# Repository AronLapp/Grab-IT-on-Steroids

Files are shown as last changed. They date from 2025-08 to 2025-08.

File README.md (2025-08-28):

# Grab-IT-on-Steroids

Making a Joy-IT Grab-it robot arm compatible with algorithm-driven control

# Purpose

This Project aims to upgrade a [Joy-IT Grab-IT](https://joy-it.net/de/products/Robot02) model robotic arm into an autonomous-ready device. In order to do so, the robot will first be supplemented with [OSRAM AS5600 Magnetic Encoders](https://ams-osram.com/products/sensor-solutions/position-sensors/ams-as5600-position-sensor) for every servo motor. The encoders' signals will be multiplexed using an [Adafruit TCA9548A I2C Multiplexer](https://learn.adafruit.com/adafruit-tca9548a-1-to-8-i2c-multiplexer-breakout/overview). An [Arduino Nano](https://store.arduino.cc/products/arduino-nano) MCU will then evaluate the encoders' positions periodically and forward them to the motion control unit consisting of an [Arduino Uno R3](https://store.arduino.cc/products/arduino-uno-rev3) and a [Joy-IT Motorino](https://joy-it.net/de/products/ARD-Moto3) shield.

Once the hardware is up and running, a RaspberryPi3 computing unit running ubuntu 22.04 Server and ROS2 Humble will be added to implement Moveit Control and autonomous behavior control.

## Parts:

- [Joy-IT Grab-IT](https://joy-it.net/de/products/Robot02)
- [Joy-IT Motorino](https://joy-it.net/de/products/ARD-Moto3)
- [Arduino Uno R3](https://store.arduino.cc/products/arduino-uno-rev3)
- [Arduino Nano](https://store.arduino.cc/products/arduino-nano)
- [OSRAM AS5600 Magnetic Encoder](https://ams-osram.com/products/sensor-solutions/position-sensors/ams-as5600-position-sensor)
- [Adafruit TCA9548A I2C Multiplexer](https://learn.adafruit.com/adafruit-tca9548a-1-to-8-i2c-multiplexer-breakout/overview)

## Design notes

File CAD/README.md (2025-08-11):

Printing was done on a [Bambulab A1 mini](https://eu.store.bambulab.com/de/products/a1-mini) 3D-Printer using [Bambulab PLA Basic](https://eu.store.bambulab.com/de/products/pla-basic-filament) Filament

All modes were created using FreeCAD and Sliced using Bambu Studio

Motor numbers are assigned ascending from bottom to top (lowest = 1, highest = 6)

I recommend starting with adding en encoder to the second motor since the encoder mount is mechanically linked to a plate that will be fastened to Motor 1 when assembling the robot.

### Attaching an Encoder to Motor 2

To add an Encoder to Motor 2, the following objects are required additionally:

- Additional parts
  - AS5600 Encoder and corresponding magnet
  - 1 M4x12mm screw
  - 4 M3x8mm screws
  - Ribbon cable (or any other cable)
- 3D-printed parts
  - 4x Motor2/basic_spacer_enc/basic_spacer.stl
  - 1x Motor2/axis_encoder/bolt_magnet_holder.stl
  - 1x Motor2/encoder_mount/general_mount_v4_3.stl
  - 1x Motor2/servo_horn_gear/servo_horn_gear.stl
  - 1x Motor2/axis_gear/axis_gear.stl

1. solder ribbon cable onto the ```encoder's``` VCC, GND, SDA and SCL
2. put ```servo_horn_gear``` on the back side of the servo horn and screw in place when adding the next segment of the robot
3. secure ```general_mount``` using the two screws that hold the motor mount in place that are further away from the axis
4. apply any kind of grease (eg. WD-40) to the middle (the slim part) of ```bolt_magnet_holder```
5. fit the slimmer edge of ```bolt_magnet_holder through``` the biggest hole in general_mount
6. add the encoder's magnet to the slot in the back of ```bolt_magnet_holder```
7. fit the four ```M3x8mm``` screws through the encoder PCB's mounting bores
8. between ```general mount``` and the ```encoder``` pcb, addd the four ```basic_spacers```.
9. screw the ```encoder``` in place
10. screw the ```M4x12``` screw through ```axis_gear``` so that the screw's head can sink into the gear
11. screw the ```m4x12``` screw attached to the ```axis_gear``` into the front side of ```bolt_magnet_holder```

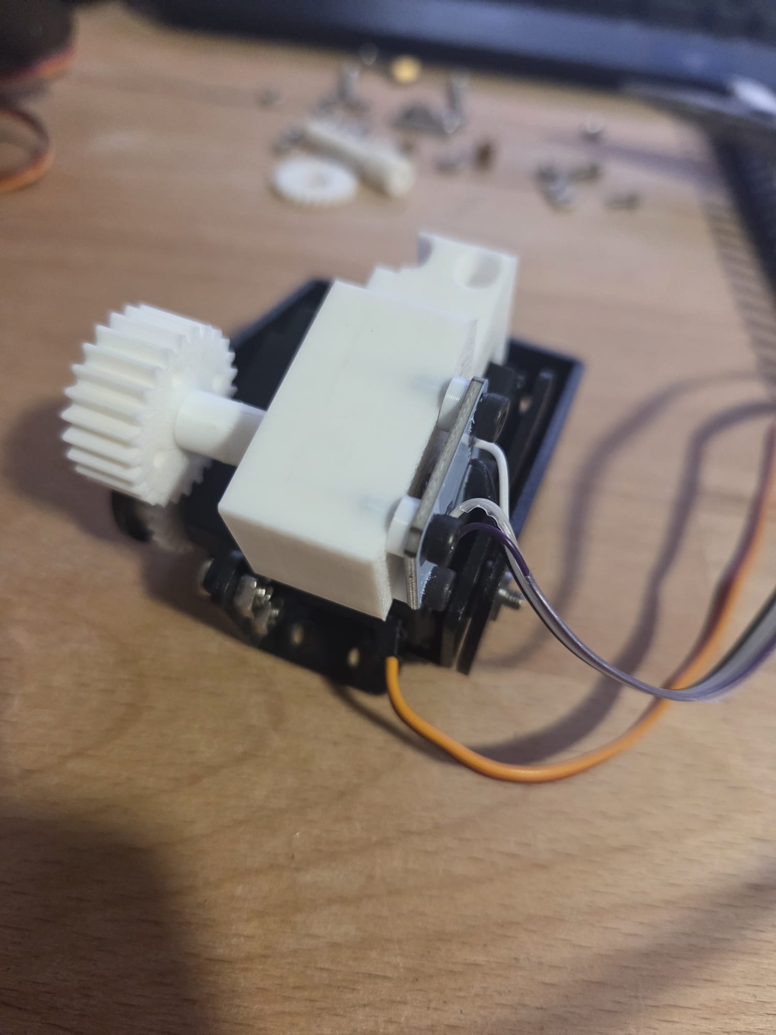
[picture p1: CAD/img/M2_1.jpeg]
Motor 2 image 1

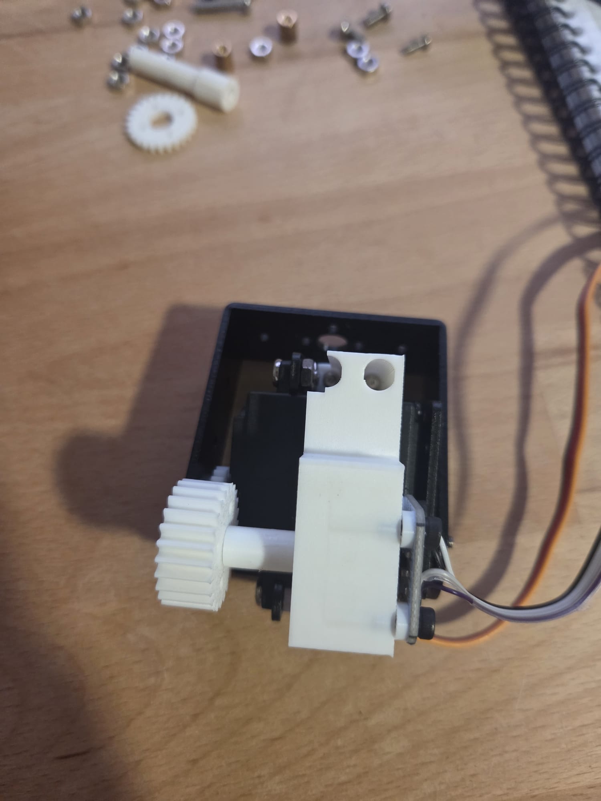
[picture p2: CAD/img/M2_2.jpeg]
Motor 2 image 2

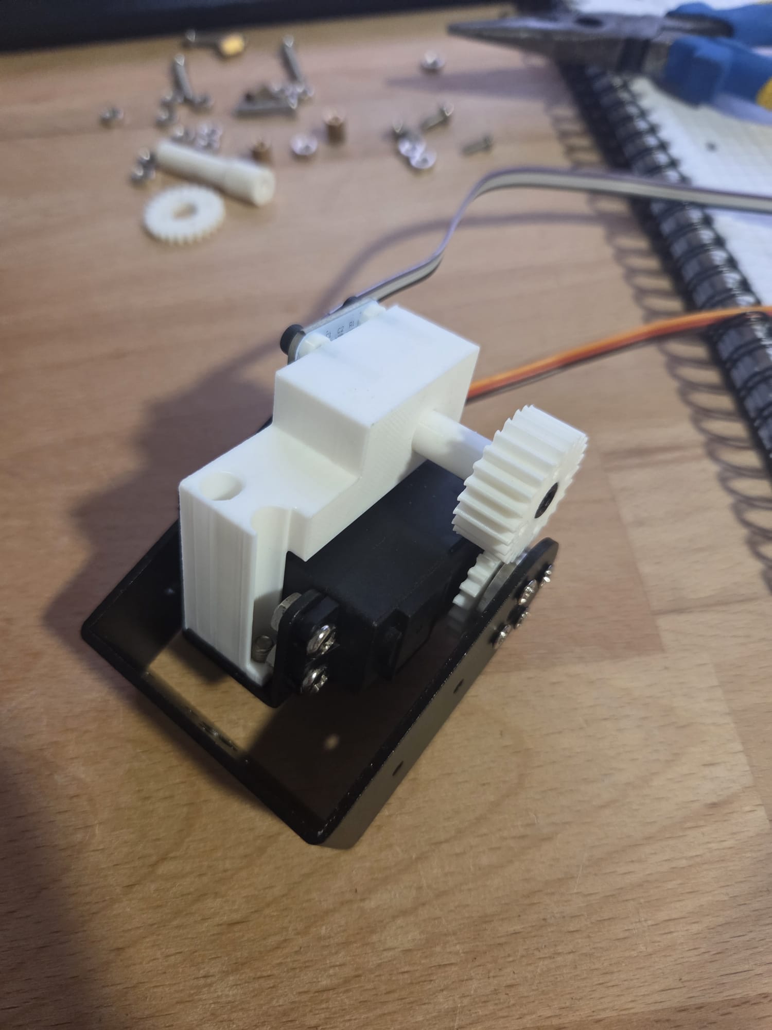
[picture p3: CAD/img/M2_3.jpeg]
Motor 2 image 3


### Attaching an Encoder to Motor 1

To add an Encoder to Motor 2, the following objects are required additionally:

- Additional parts
  - AS5600 Encoder and corresponding magnet
  - 1x M4x12mm screw
  - 4x M4x16mm screws
  - 4x M3x8mm screws
  - 4x M4 nuts
  - Ribbon cable (or any other cable)
- 3D-printed parts
  - 1x Motor1/axis/axis.stl
  - 1x Motor1/axis_gear/axis_gear.stl
  - 4x Motor1/basic_spacer_enc/basic_spacer.stl
  - 1x Motor1/encoder_mount/encoder_mount.stl
  - 1x Motor1/servo_horn_gear/servo_horn_gear.stl

1. solder ribbon cable onto the ```encoder's``` VCC, GND, SDA and SCL
2. put ```servo_horn_gear``` on the back size of the servo horn and screw in place when adding the next segment of the robot
3. fit the long screws that connect the base plate and the bearing through the bores in ```encoder_mount```
4. fit ```axis``` through ```encoder_mount```, add magnet into the bore on the lower side of the axis
5. fit the top end of ```axis``` through the plate that holds Motor1 and screw ```axis_gear``` in place using a ```M4x12mm``` screw
6. screw the ```encoder``` in place using the 4 ```m3x8mm``` screws and the 4```encoder_mounts```
7. proceed building the robot using the official manual, replace the longer screws used on page11 by 4```m4x16mm``` screws and M4 nuts in order to ensure clearance for ```axis_gear```

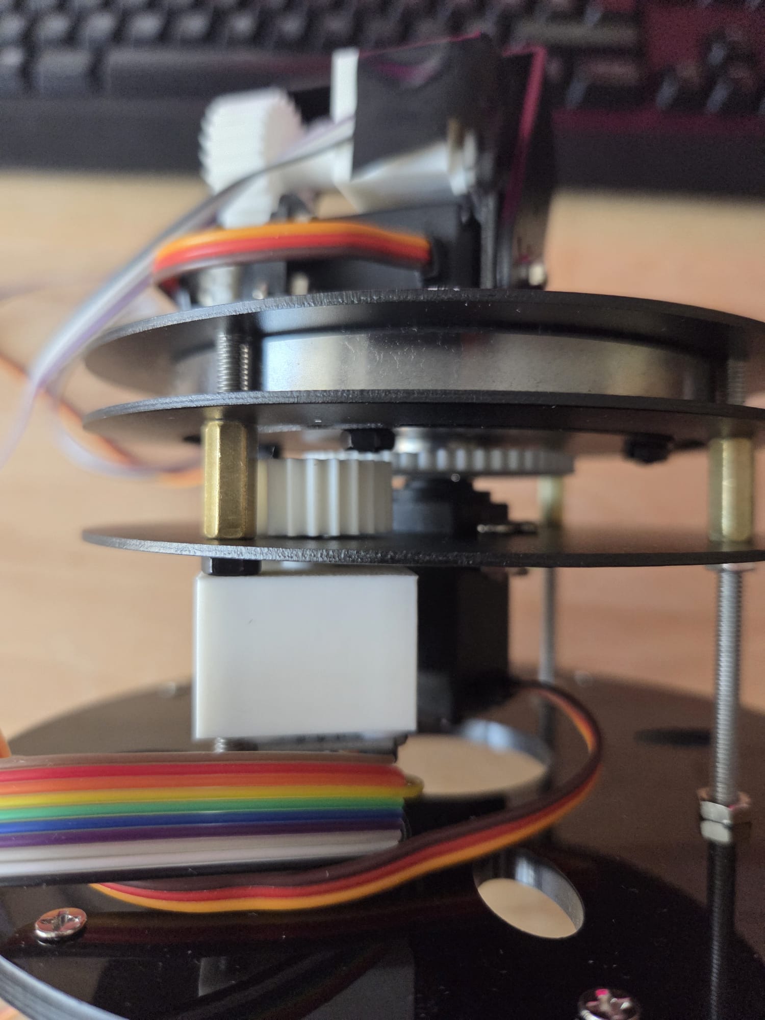
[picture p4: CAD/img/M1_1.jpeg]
Motor 1 image 1

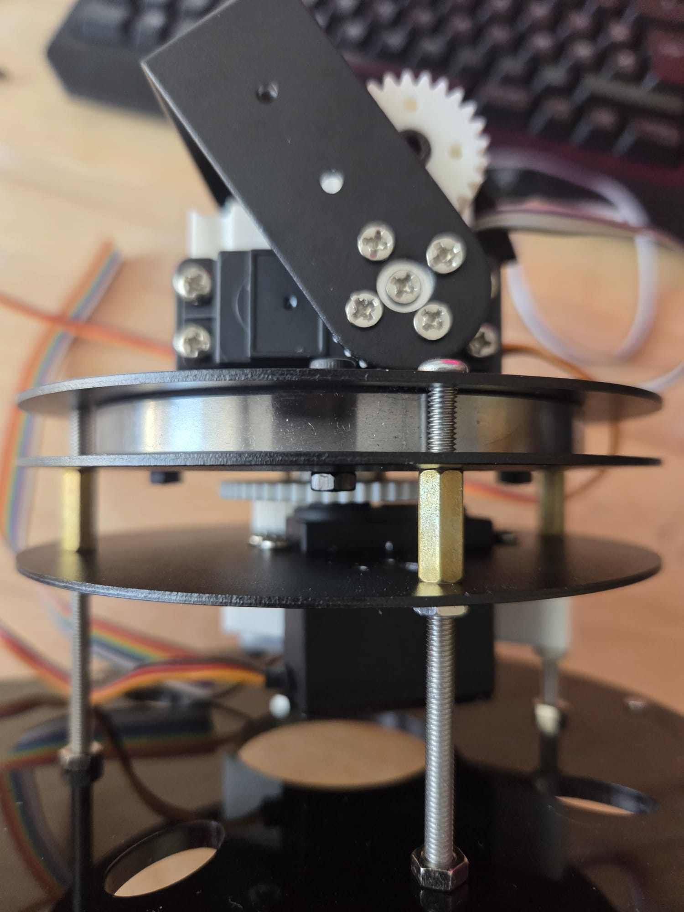
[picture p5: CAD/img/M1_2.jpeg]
Motor 1 image 2


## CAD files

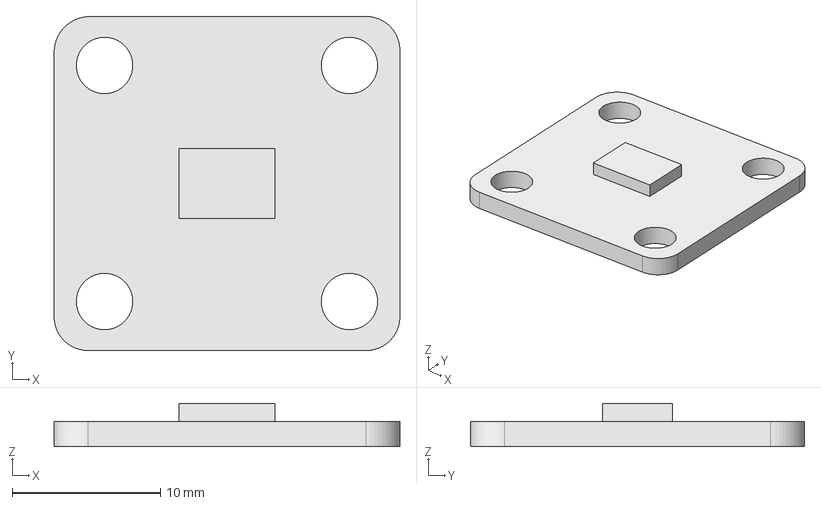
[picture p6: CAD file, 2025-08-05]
CAD/AS5600_Breakout_Model/AS5600_model.FCStd
23.3 x 22.5 x 2.90 mm

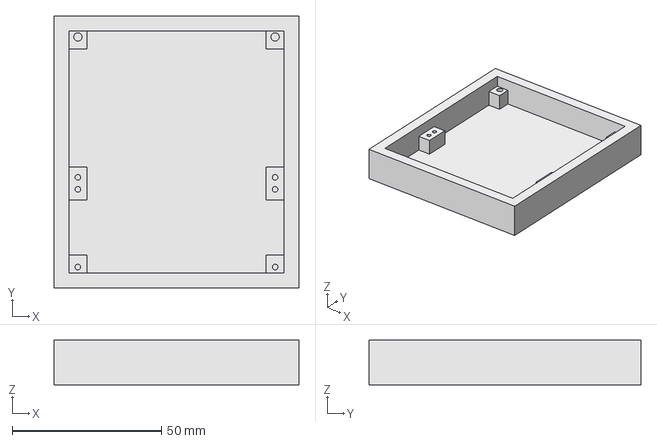
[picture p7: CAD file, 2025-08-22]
CAD/circuitboard_enclosure/circuitboard_case.FCStd
82.0 x 91.0 x 15.0 mm

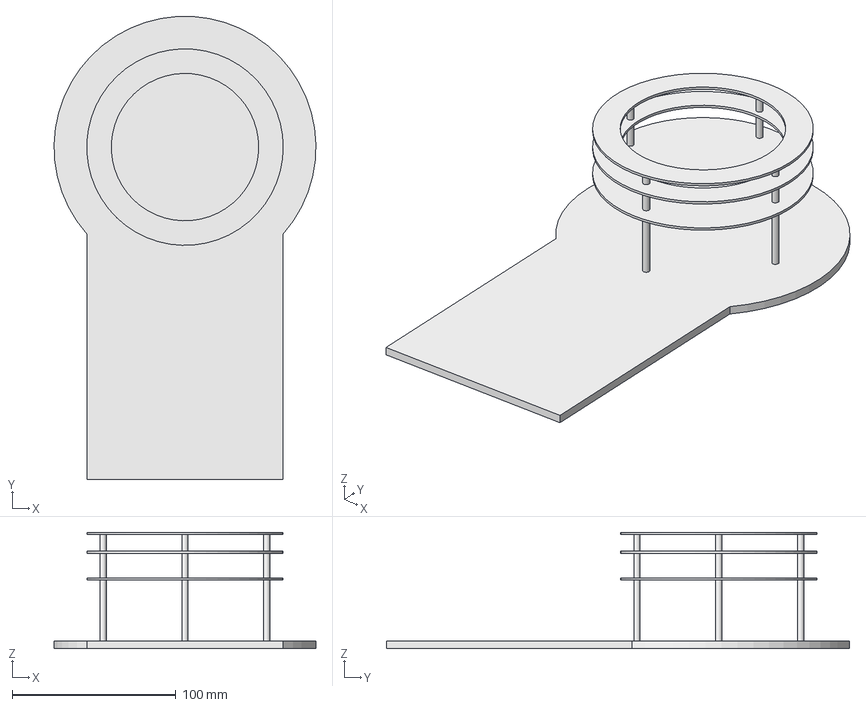
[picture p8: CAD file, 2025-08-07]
CAD/Grab-IT/Baseplate/Grab-IT.FCStd
160.0 x 282.8 x 71.0 mm

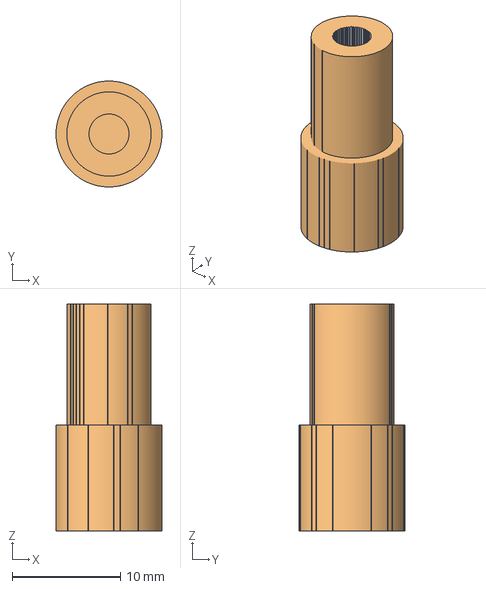
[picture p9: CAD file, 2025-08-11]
CAD/Motor1/axis/axis.FCStd
9.80 x 9.80 x 21.0 mm
Body (Meshed)

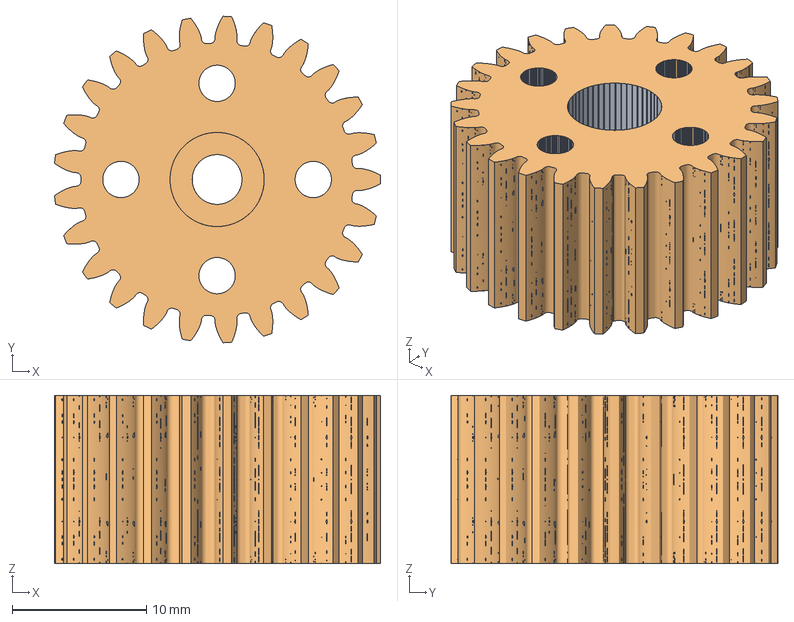
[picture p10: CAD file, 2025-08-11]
CAD/Motor1/axis_gear/axis_gear.FCStd
24.2 x 24.3 x 12.5 mm
Body (Meshed)

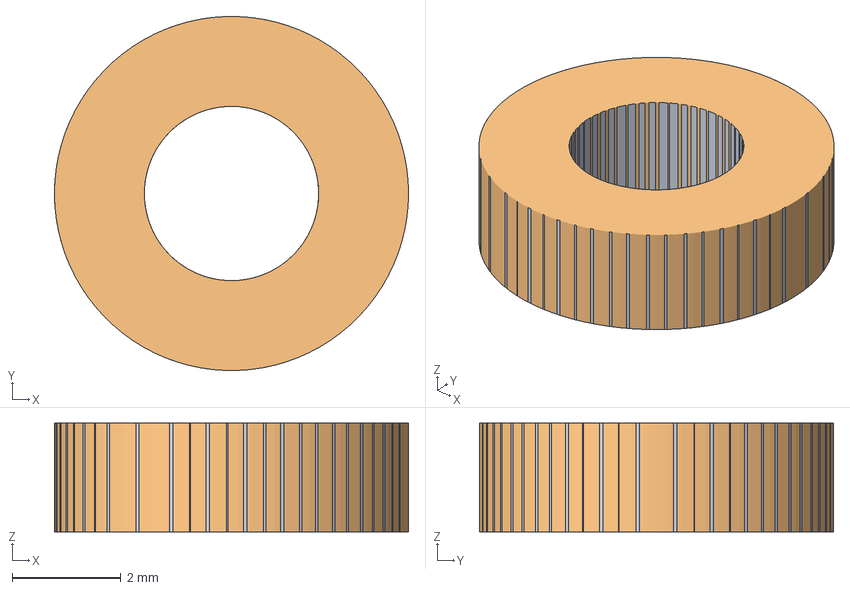
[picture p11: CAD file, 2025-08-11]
CAD/Motor1/basic_spacer_enc/basic_spacer.FCStd
6.50 x 6.50 x 2.00 mm
Body (Meshed)

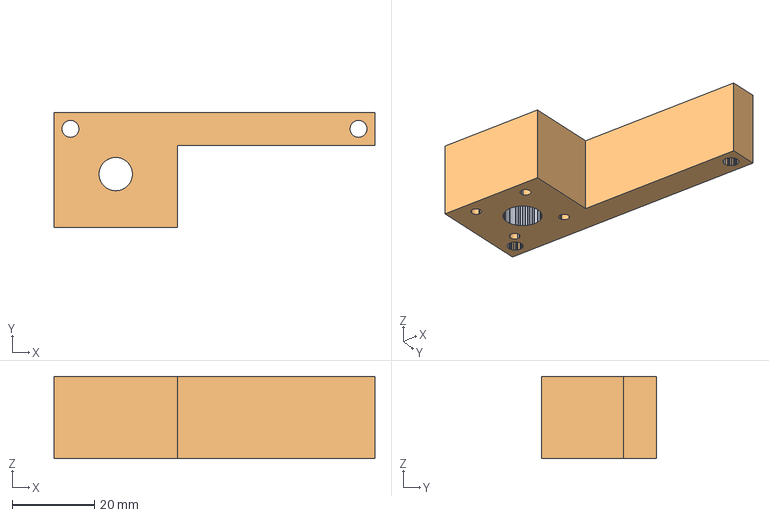
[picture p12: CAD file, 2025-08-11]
CAD/Motor1/encoder_mount/encoder_mount.FCStd
78.0 x 28.0 x 20.0 mm
Body (Meshed)

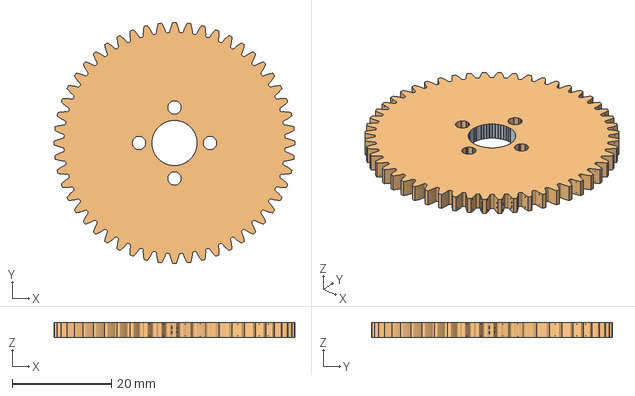
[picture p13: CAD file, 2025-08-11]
CAD/Motor1/servo_horn_gear/servo_horn_gear.FCStd
48.6 x 48.6 x 3.10 mm
Body (Meshed)

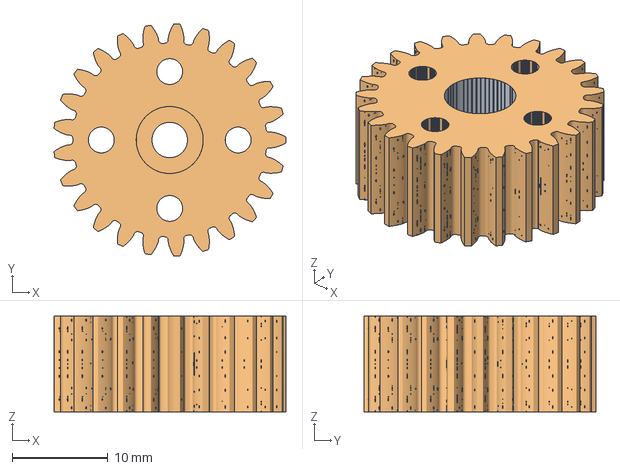
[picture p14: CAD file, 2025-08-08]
CAD/Motor2/axis_gear/axis_gear.FCStd
24.2 x 24.3 x 10.0 mm
Body (Meshed)

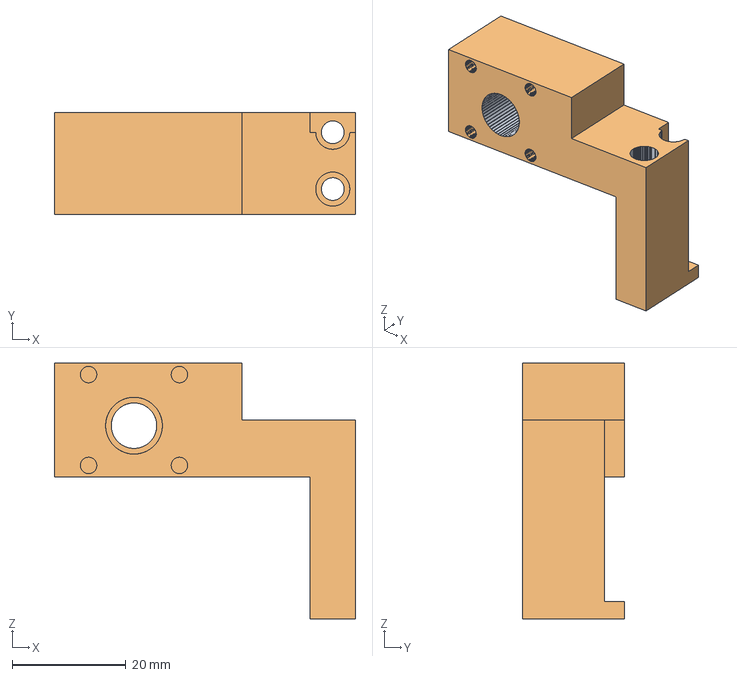
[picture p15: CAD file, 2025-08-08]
CAD/Motor2/encoder_mount/v4.3.FCStd
53.0 x 18.0 x 45.0 mm
Body (Meshed)

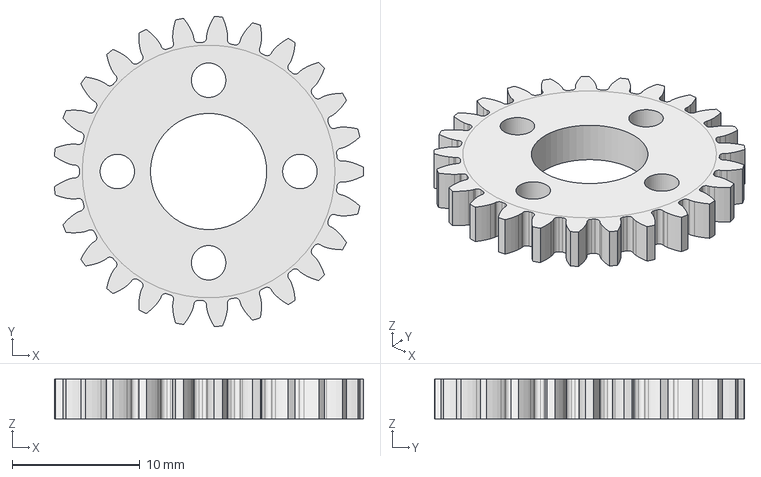
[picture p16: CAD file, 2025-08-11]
CAD/Motor2/servo_horn_gear/servo_horn_gear.FCStd
24.2 x 24.3 x 3.10 mm

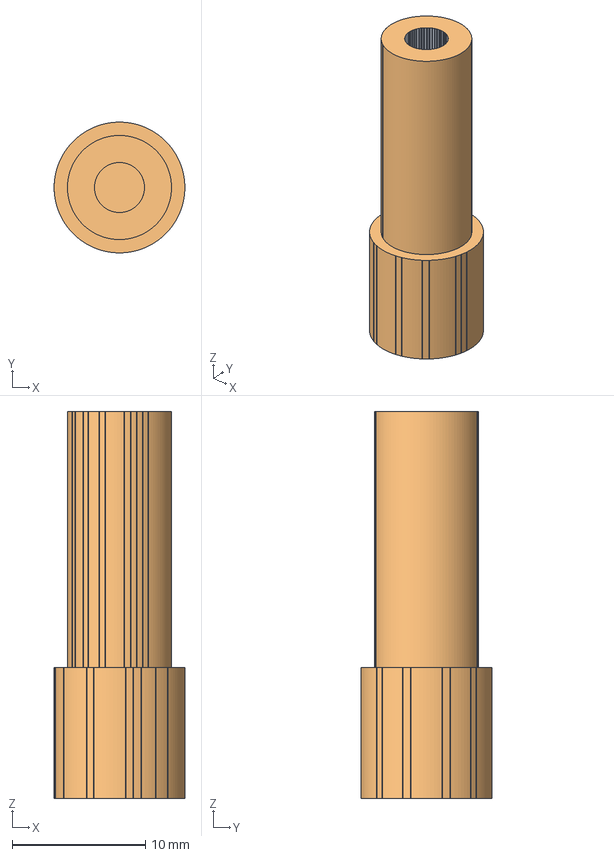
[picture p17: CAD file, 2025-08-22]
CAD/Motor3/axis/axis.FCStd
9.80 x 9.80 x 29.0 mm
Body (Meshed)

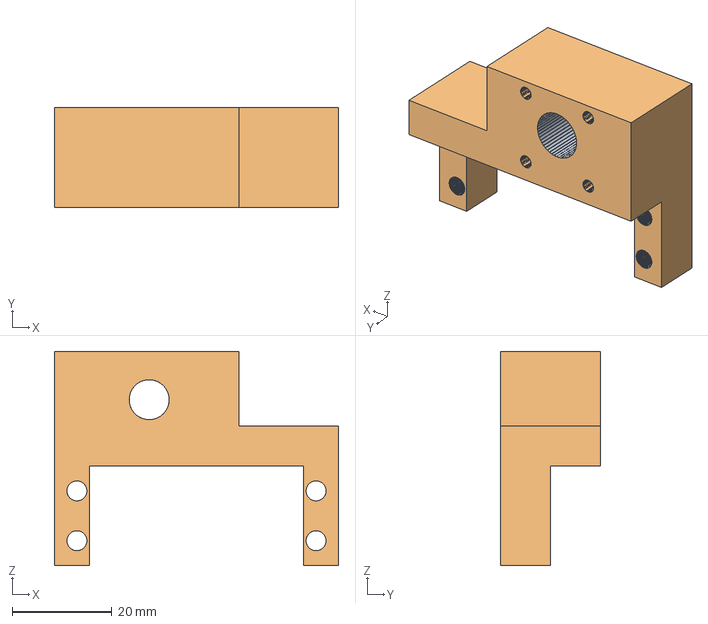
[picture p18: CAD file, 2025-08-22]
CAD/Motor3/encoder_mount/encoder_mount.FCStd
57.0 x 20.0 x 43.0 mm
Body (Meshed)

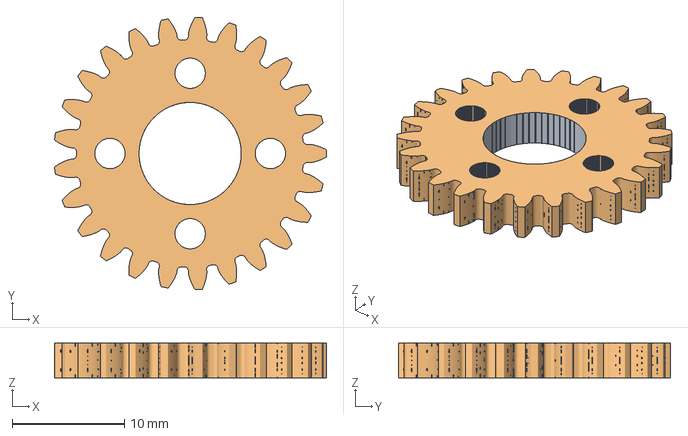
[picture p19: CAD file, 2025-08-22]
CAD/Motor3/servo_horn_gear/servo_horn_gear.FCStd
24.2 x 24.3 x 3.10 mm
Body (Meshed)

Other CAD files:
CAD/Motor2/basic_spacer_enc/basic_spacer.FCStd
CAD/Motor3/axis_gear/axis_gear.FCStd
CAD/Motor3/basic_spacer_enc/basic_spacer.FCStd
CAD/Motor1/axis/axis.stl
CAD/Motor1/axis_gear/axis_gear.stl
CAD/Motor1/basic_spacer_enc/basic_spacer.stl
CAD/Motor1/encoder_mount/encoder_mount.stl
CAD/Motor1/servo_horn_gear/servo_horn_gear.stl
CAD/Motor2/axis_encoder/bolt_magnet_holder.FCStd
CAD/Motor2/axis_encoder/bolt_magnet_holder.stl
CAD/Motor2/axis_gear/axis_gear.stl
CAD/Motor2/basic_spacer_enc/basic_spacer.stl
CAD/Motor2/encoder_mount/general_mount_v4_3.stl
CAD/Motor2/servo_horn_gear/servo_horn_gear.stl
CAD/Motor3/axis/axis.stl
CAD/Motor3/axis_gear/axis_gear.stl
CAD/Motor3/basic_spacer_enc/basic_spacer_enc.stl
CAD/Motor3/encoder_mount/encoder_mount.stl
CAD/Motor3/servo_horn_gear/servo_horn_gear.stl
CAD/Motor4/axis/axis.stl
CAD/Motor4/axis_gear/axis_gear.FCStd
CAD/Motor4/axis_gear/axis_gear.stl
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

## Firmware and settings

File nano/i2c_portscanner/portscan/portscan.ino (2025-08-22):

#include <Wire.h>

#define TCA_ADDR 0x70
#define I2C_MIN  0x03
#define I2C_MAX  0x77

void tcaSelect(uint8_t channel) {
  if (channel > 7) return;
  Wire.beginTransmission(TCA_ADDR);
  Wire.write(1 << channel);
  Wire.endTransmission();
}

bool tcaPresent() {
  Wire.beginTransmission(TCA_ADDR);
  return (Wire.endTransmission() == 0);
}

void setup() {
  Serial.begin(115200);
  while (!Serial) {}

  Wire.begin();
  Wire.setClock(100000);     // 100kHz standard bus speed

  Serial.println(F("\n=== TCA9548A I2C-Multichannel-Scanner ==="));
  Serial.print(F("TCA-Address: 0x"));
  Serial.println(TCA_ADDR, HEX);

  if (!tcaPresent()) {
    Serial.println(F("[WARN] TCA9548A not reachable. Check wiring and address"));
  }
}

void loop() {
  for (uint8_t ch = 0; ch < 8; ch++) {
    tcaSelect(ch);
    delay(2);

    Serial.print(F("\nChannel "));
    Serial.print(ch);
    Serial.println(F(":"));

    uint8_t found = 0;

    for (uint8_t addr = I2C_MIN; addr <= I2C_MAX; addr++) {
      if (addr == TCA_ADDR) continue; // Skipt TCA9548A Module

      Wire.beginTransmission(addr);
      uint8_t error = Wire.endTransmission();

      if (error == 0) {
        Serial.print(F("  -> found at 0x"));
        if (addr < 16) Serial.print('0');
        Serial.print(addr, HEX);
        Serial.print(F(" (dec "));
        Serial.print(addr, DEC);
        Serial.println(F(")"));
        found++;
      } else if (error == 4) {
        Serial.print(F("[WARNING] Unknown error at address 0x"));
        if (addr < 16) Serial.print('0');
        Serial.println(addr, HEX);
      }
    }

    if (found == 0) {
      Serial.println(F("  (no devices)"));
    }
  }

  Serial.println(F("\nScan complete. Re-scanning in 5 seconds"));
  delay(5000);
}

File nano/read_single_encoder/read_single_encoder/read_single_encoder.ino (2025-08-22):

#include <Wire.h>
#include <Adafruit_AS5600.h>

#define TCA_ADDR     0x70
#define ENCODER_CH   0 // Adjust according to Encoder's mounted channel at TCA9548A
#define AS5600_ADDR  0x36 // AS5600 I2C-Address

// AS5600 statusregisters
#define AS5600_REG_STATUS 0x0B
#define AS5600_STATUS_MD  (1 << 5)
#define AS5600_STATUS_ML  (1 << 4)
#define AS5600_STATUS_MH  (1 << 3)

Adafruit_AS5600 as5600;

void tcaSelect(uint8_t channel) {
  if (channel > 7) return;
  Wire.beginTransmission(TCA_ADDR);
  Wire.write(1 << channel);
  Wire.endTransmission();
}

// read 8 bits using i2c
uint8_t i2cRead8(uint8_t addr, uint8_t reg){
  Wire.beginTransmission(addr); Wire.write(reg);
  Wire.endTransmission(false);
  Wire.requestFrom(addr, (uint8_t)1);
  return Wire.available() ? Wire.read() : 0;
}

static inline float ticksToDeg(uint16_t ticks){
  return ticks * (360.0f / 4096.0f);
}

void setup() {
  Serial.begin(115200);
  delay(200);

  Wire.begin();
  Wire.setClock(100000); // 100 kHz standard bus speed

  tcaSelect(ENCODER_CH);
  delay(2);

  if (!as5600.begin(AS5600_ADDR)) {
    Serial.println(F("[ERROR] AS5600 not found. Check TCA channel, wiring, address."));
    while (1) delay(100);
  }

  Serial.println(F("AS5600 found on TCA channel 1. Start logging status.."));
}

void loop() {
  tcaSelect(ENCODER_CH);

  // Raw angle (0..4095) and 0..360 deg
  uint16_t rawTicks = as5600.getRawAngle() & 0x0FFF;
  float angleDeg = ticksToDeg(rawTicks);

  // Field strength / status
  uint8_t agc     = as5600.getAGC();        // 0..255 (AS5600 uses 0..255)
  uint16_t mag    = as5600.getMagnitude();  // 0..4095
  uint8_t status  = i2cRead8(AS5600_ADDR, AS5600_REG_STATUS);
  bool MD = status & AS5600_STATUS_MD;      // Magnet found
  bool ML = status & AS5600_STATUS_ML;      // Field strength too low
  bool MH = status & AS5600_STATUS_MH;      // Field strength too high

  Serial.print(F("ch")); Serial.print(ENCODER_CH);
  Serial.print(F("  angle=")); Serial.print(angleDeg, 2); Serial.print(F("°"));
  Serial.print(F("  raw="));   Serial.print(rawTicks);
  Serial.print(F("  AGC="));   Serial.print((int)agc);
  Serial.print(F("  MAG="));   Serial.print(mag);
  Serial.print(F("  ["));
  if (MD) Serial.print(F("MD "));
  if (ML) Serial.print(F("ML "));
  if (MH) Serial.print(F("MH "));
  Serial.println(F("]"));
  
  if (ML) Serial.println(F("Hint: Field strength too low"));
  if (MH) Serial.println(F("Hint: Field strength too high"));

  delay(100); // ~10 Hz
}

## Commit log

2025-08-05 init git, add first CAD model
    [AS5600_model.FCStd]
2025-08-07 added Grab-IT baseplate CAD
    [Grab-IT.FCStd]
2025-08-08 finish encoder Motor 2
    [axis_gear.FCStd, axis_gear.stl, basic_spacer.FCStd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]
2025-08-11 added Motor1 STLs, update readme
    [axis.FCStd, axis.stl, axis_gear.FCStd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]
2025-08-13 CAD done
    [axis.FCStd, axis.stl, axis_gear.FCStd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]
2025-08-22 added mount for soldered circuit board
    [circuitboard_case.3mf, circuitboard_case.FCStd, circuitboard_case.stl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]
2025-08-26 added UART communication test for nano
2025-08-26 added uno UART comm test
